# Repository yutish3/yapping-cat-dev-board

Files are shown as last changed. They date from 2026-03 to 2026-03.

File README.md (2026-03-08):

this is a custom made esp 32 devboard with extra 128mbit memory so it can do a little more processing then normal
it also has intigrted sensors for temprature and gyromovement sd card slot andd headphone jack
this will fit my custom need of small yet powerful enough custom devboard







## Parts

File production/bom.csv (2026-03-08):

Designator | Footprint | Quantity | Value | LCSC Part #
C1, C15, C16, C17, C18, C2, C21, C22, C23, C24, C25, C26, C3, C4, C5, C6 | 0603 | 16 | 100nF
C10, C11, C12, C13, C9 | 0603 | 5 | 10µF
C14 | 0603 | 1 | 22µF
C19, C20 | 0603 | 2 | 2.2µF
C7, C8 | 0603 | 2 | 22pF
D1 | LED_WS2812B_PLCC4_5.0x5.0mm_P3.2mm | 1 | WS2812B
J1 | USB_C_Receptacle_Amphenol_124019772112A | 1 | USB_C_Receptacle_USB2.0_14P
J2 | JST_PH_S2B-PH-SM4-TB_1x02-1MP_P2.00mm_Horizontal | 1 | Conn_01x02
J3 | microSD_HC_Hirose_DM3AT-SF-PEJM5 | 1 | Micro_SD_Card
J4 | Jack_3.5mm_CUI_SJ-3523-SMT_Horizontal | 1 | AudioJack3
J5 | U.FL_Hirose_U.FL-R-SMT-1_Vertical | 1 | Conn_Coaxial
J6, J7 | PinHeader_1x02_P2.54mm_Vertical | 2 | Conn_01x02
J8 | PinHeader_1x13_P2.54mm_Vertical | 1 | Conn_01x13
L1 | L_6.3x6.3_H3 | 1 | 2.2uH
R1, R2 | 0603 | 2 | 5.1k
R10, R11, R12, R13, R14, R5, R6, R7, R8, R9 | 0603 | 10 | 10k
R3 | 0603 | 1 | 1.5k
R4 | 0603 | 1 | 1.1k
SW1 | SW_SPST_FSMSM | 1 | boot
SW2 | SW_SPST_FSMSM | 1 | reset
U1 | QFN-56-1EP_7x7mm_P0.4mm_EP4x4mm | 1 | ESP32-S3
U2 | WSON-8-1EP_6x5mm_P1.27mm_EP3.4x4.3mm | 1 | W25Q128JVP
U3 | VQFN-16-1EP_3x3mm_P0.5mm_EP1.6x1.6mm | 1 | BQ24072RGT
U4 | Texas_DRC0010J_ThermalVias | 1 | TPS63001
U5 | TSSOP-20_4.4x6.5mm_P0.65mm | 1 | PCM5102A
U6 | Bosch_LGA-8_2.5x2.5mm_P0.65mm_ClockwisePinNumbering | 1 | BME280
U7 | LGA-14_3x2.5mm_P0.5mm_LayoutBorder3x4y | 1 | LSM6DS3
Y1 | Crystal_SMD_3225-4Pin_3.2x2.5mm | 1 | 40MHz

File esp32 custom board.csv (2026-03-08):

Reference | Qty | Value | DNP | Exclude from BOM | Exclude from Board | Footprint | Datasheet
C1,C2,C3,C4,C5,C6,C15,C16,C17,C18,C21,C22,C23,C24,C25,C26 | 16 | 100nF |  |  |  | Capacitor_SMD:C_0603_1608Metric | ~
C7,C8 | 2 | 22pF |  |  |  | Capacitor_SMD:C_0603_1608Metric | ~
C9,C10,C11,C12,C13 | 5 | 10µF |  |  |  | Capacitor_SMD:C_0603_1608Metric | ~
C14 | 1 | 22µF |  |  |  | Capacitor_SMD:C_0603_1608Metric | ~
C19,C20 | 2 | 2.2µF |  |  |  | Capacitor_SMD:C_0603_1608Metric | ~
D1 | 1 | WS2812B |  |  |  | LED_SMD:LED_WS2812B_PLCC4_5.0x5.0mm_P3.2mm | https://cdn-shop.adafruit.com/datasheets/WS2812B.pdf
J1 | 1 | USB_C_Receptacle_USB2.0_14P |  |  |  | Connector_USB:USB_C_Receptacle_Amphenol_124019772112A | https://www.usb.org/sites/default/files/documents/usb_type-c.zip
J2 | 1 | Conn_01x02 |  |  |  | Connector_JST:JST_PH_S2B-PH-SM4-TB_1x02-1MP_P2.00mm_Horizontal | ~
J3 | 1 | Micro_SD_Card |  |  |  | Connector_Card:microSD_HC_Hirose_DM3AT-SF-PEJM5 | https://www.we-online.com/components/products/datasheet/693072010801.pdf
J4 | 1 | AudioJack3 |  |  |  | Connector_Audio:Jack_3.5mm_CUI_SJ-3523-SMT_Horizontal | ~
J5 | 1 | Conn_Coaxial |  |  |  | Connector_Coaxial:U.FL_Hirose_U.FL-R-SMT-1_Vertical | ~
J6,J7 | 2 | Conn_01x02 |  |  |  | Connector_PinHeader_2.54mm:PinHeader_1x02_P2.54mm_Vertical | ~
J8 | 1 | Conn_01x13 |  |  |  | Connector_PinHeader_2.54mm:PinHeader_1x13_P2.54mm_Vertical | ~
L1 | 1 | 2.2uH |  |  |  | Inductor_SMD:L_6.3x6.3_H3 | ~
R1,R2 | 2 | 5.1k |  |  |  | Resistor_SMD:R_0603_1608Metric | ~
R3 | 1 | 1.5k |  |  |  | Resistor_SMD:R_0603_1608Metric | ~
R4 | 1 | 1.1k |  |  |  | Resistor_SMD:R_0603_1608Metric | ~
R5,R11,R12 | 3 | 10K |  |  |  | Resistor_SMD:R_0603_1608Metric | ~
R6,R7,R8,R9,R10,R13,R14 | 7 | 10k |  |  |  | Resistor_SMD:R_0603_1608Metric | ~
SW1 | 1 | boot |  |  |  | Button_Switch_SMD:SW_SPST_FSMSM | ~
SW2 | 1 | reset |  |  |  | Button_Switch_SMD:SW_SPST_FSMSM | ~
U1 | 1 | ESP32-S3 |  |  |  | Package_DFN_QFN:QFN-56-1EP_7x7mm_P0.4mm_EP4x4mm | https://www.espressif.com/sites/default/files/documentation/esp32-s3_datasheet_en.pdf
U2 | 1 | W25Q128JVP |  |  |  | Package_SON:WSON-8-1EP_6x5mm_P1.27mm_EP3.4x4.3mm | https://www.winbond.com/resource-files/w25q128jv_dtr%20revc%2003272018%20plus.pdf
U3 | 1 | BQ24072RGT |  |  |  | Package_DFN_QFN:VQFN-16-1EP_3x3mm_P0.5mm_EP1.6x1.6mm | http://www.ti.com/lit/ds/symlink/bq24072.pdf
U4 | 1 | TPS63001 |  |  |  | Package_SON:Texas_DRC0010J_ThermalVias | http://www.ti.com/lit/ds/symlink/tps63000.pdf
U5 | 1 | PCM5102A |  |  |  | Package_SO:TSSOP-20_4.4x6.5mm_P0.65mm | https://www.ti.com/lit/ds/symlink/pcm5102a.pdf
U6 | 1 | BME280 |  |  |  | Package_LGA:Bosch_LGA-8_2.5x2.5mm_P0.65mm_ClockwisePinNumbering | https://www.bosch-sensortec.com/media/boschsensortec/downloads/datasheets/bst-bme280-ds002.pdf
U7 | 1 | LSM6DS3 |  |  |  | Package_LGA:LGA-14_3x2.5mm_P0.5mm_LayoutBorder3x4y | https://www.st.com/resource/en/datasheet/lsm6ds3tr-c.pdf
Y1 | 1 | 40MHz |  |  |  | Crystal:Crystal_SMD_3225-4Pin_3.2x2.5mm | ~

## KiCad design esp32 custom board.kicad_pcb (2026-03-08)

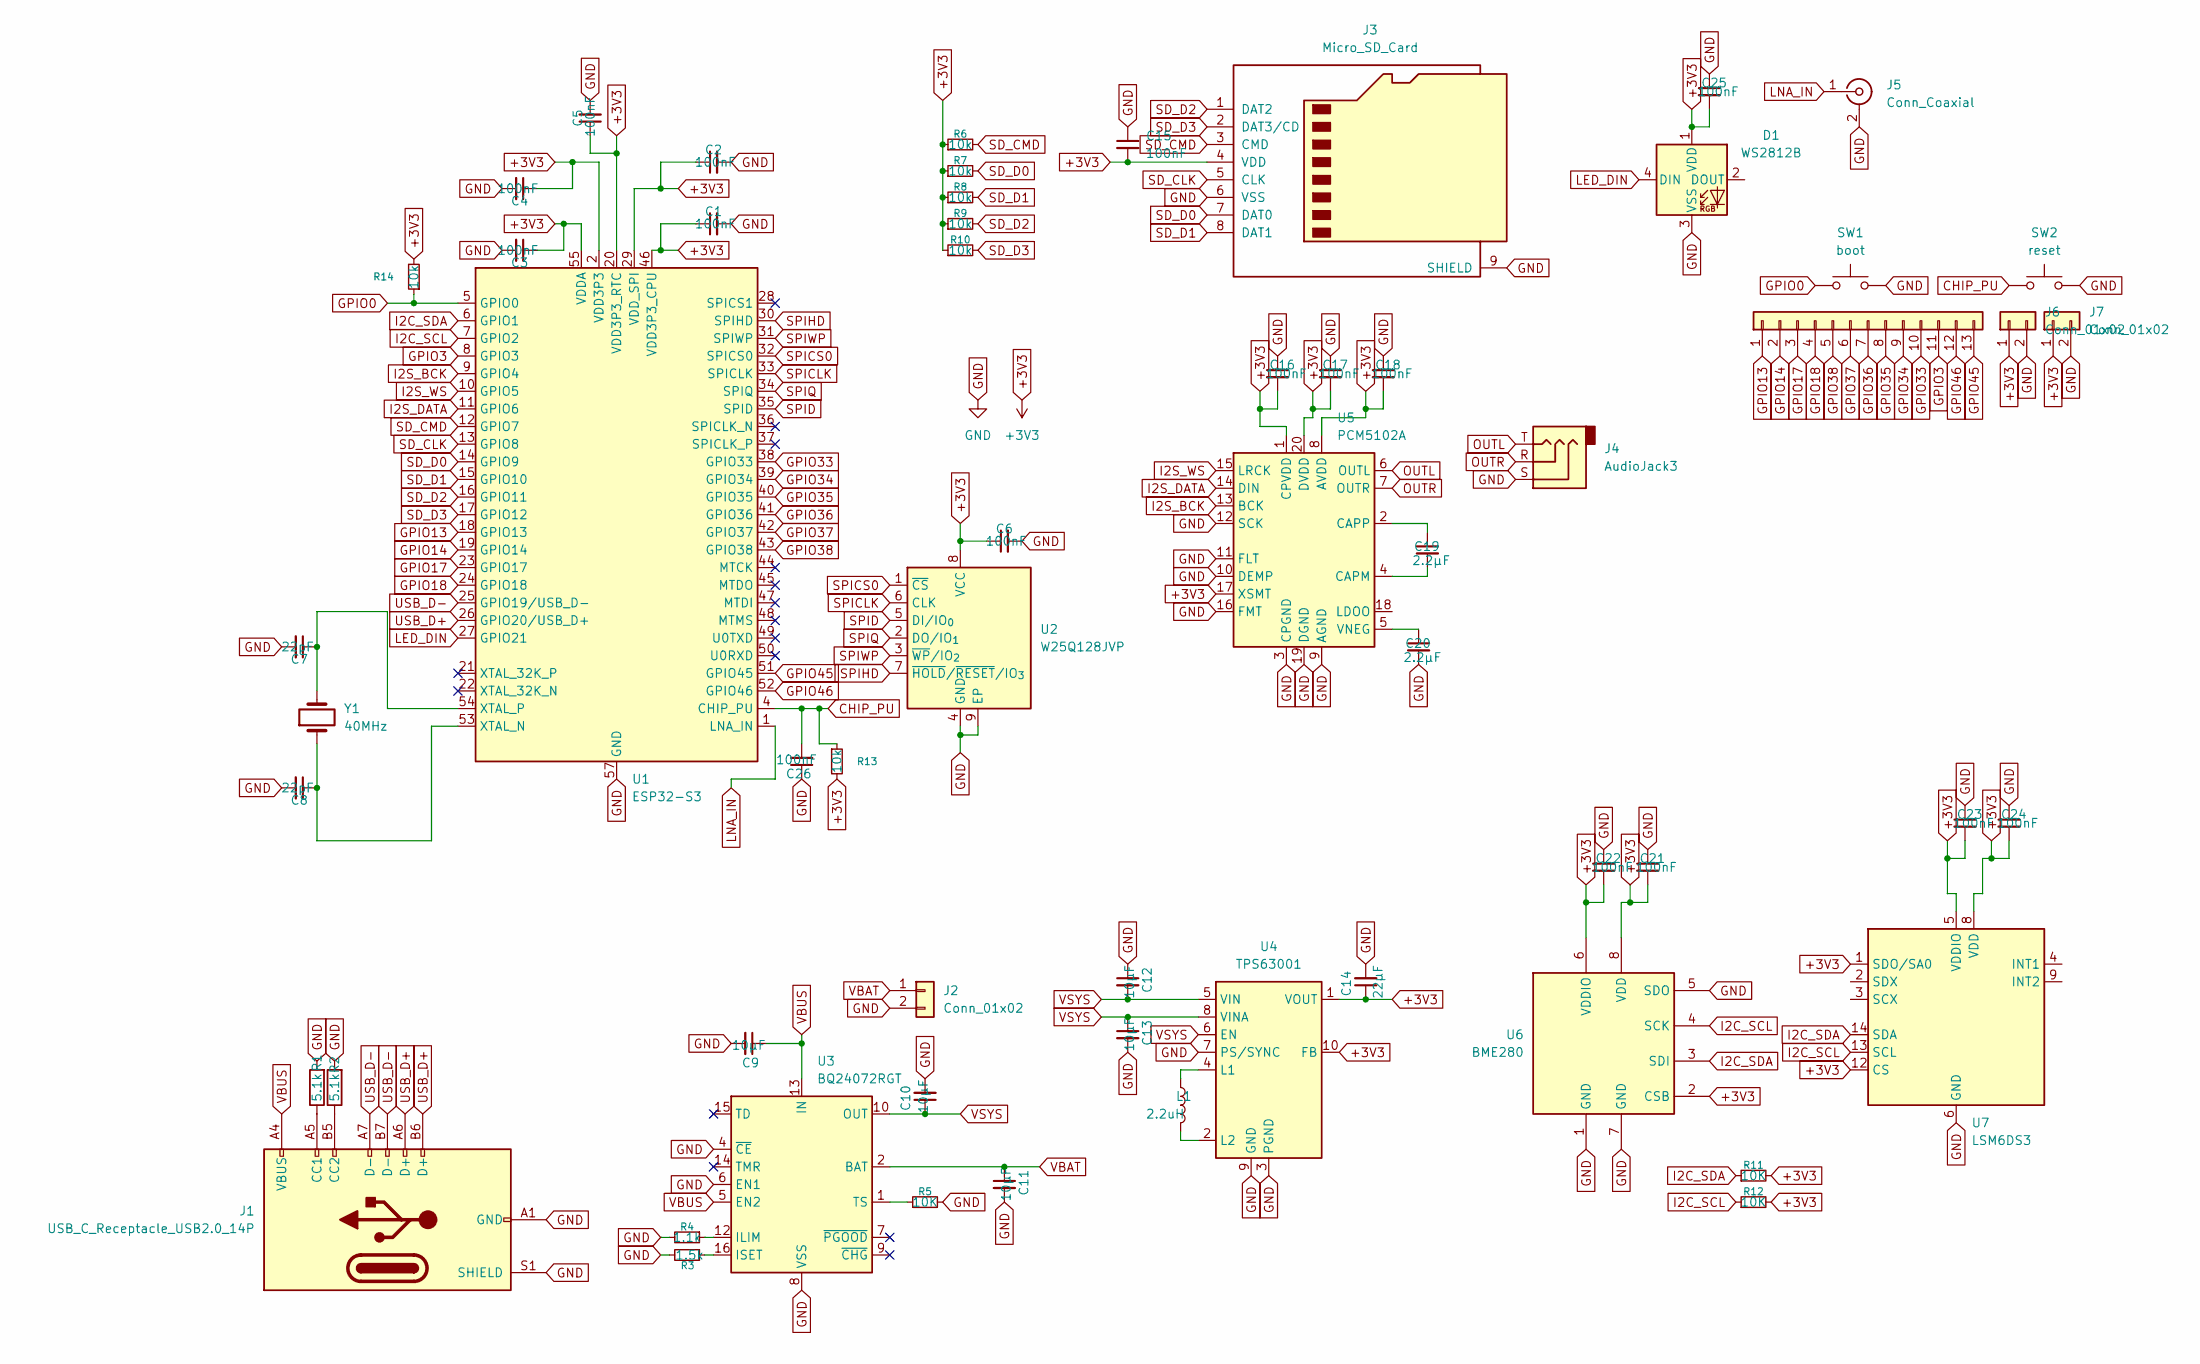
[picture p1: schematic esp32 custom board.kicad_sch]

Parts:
C1, C2, C3, C4, C5, C6, C15, C16, C17, C18, C21, C22, C23, C24, C25, C26: 100nF; C_0603_1608Metric
C7, C8: 22pF; C_0603_1608Metric
C9, C10, C11, C12, C13: 10µF; C_0603_1608Metric
C14: 22µF; C_0603_1608Metric
C19, C20: 2.2µF; C_0603_1608Metric
D1: WS2812B; LED_WS2812B_PLCC4_5.0x5.0mm_P3.2mm
J1: USB_C_Receptacle_USB2.0_14P; USB_C_Receptacle_Amphenol_124019772112A
J2: Conn_01x02; JST_PH_S2B-PH-SM4-TB_1x02-1MP_P2.00mm_Horizontal
J3: Micro_SD_Card; microSD_HC_Hirose_DM3AT-SF-PEJM5
J4: AudioJack3; Jack_3.5mm_CUI_SJ-3523-SMT_Horizontal
J5: Conn_Coaxial; U.FL_Hirose_U.FL-R-SMT-1_Vertical
J6, J7: Conn_01x02; PinHeader_1x02_P2.54mm_Vertical
J8: Conn_01x13; PinHeader_1x13_P2.54mm_Vertical
L1: 2.2uH; L_6.3x6.3_H3
R1, R2: 5.1k; R_0603_1608Metric
R3: 1.5k; R_0603_1608Metric
R4: 1.1k; R_0603_1608Metric
R5, R11, R12: 10K; R_0603_1608Metric
R6, R7, R8, R9, R10, R13, R14: 10k; R_0603_1608Metric
SW1: boot; SW_SPST_FSMSM
SW2: reset; SW_SPST_FSMSM
U1: ESP32-S3; QFN-56-1EP_7x7mm_P0.4mm_EP4x4mm
U2: W25Q128JVP; WSON-8-1EP_6x5mm_P1.27mm_EP3.4x4.3mm
U3: BQ24072RGT; VQFN-16-1EP_3x3mm_P0.5mm_EP1.6x1.6mm
U4: TPS63001; Texas_DRC0010J_ThermalVias
U5: PCM5102A; TSSOP-20_4.4x6.5mm_P0.65mm
U6: BME280; Bosch_LGA-8_2.5x2.5mm_P0.65mm_ClockwisePinNumbering
U7: LSM6DS3; LGA-14_3x2.5mm_P0.5mm_LayoutBorder3x4y
Y1: 40MHz; Crystal_SMD_3225-4Pin_3.2x2.5mm

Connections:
+3V3: C1.1, C2.1, C3.1, C4.1, C5.1, C6.1, C14.1, C15.2, C16.2, C17.2, C18.2, C21.2, C22.2, C23.2, C24.2, C25.2, D1.1 (VDD), J3.4 (VDD), J6.1, J7.1, R6.1, R7.1, R8.1, R9.1, R10.1, R11.2, R12.2, R13.2, R14.2, U1.2 (VDD3P3), U1.3 (VDD3P3), U1.20 (VDD3P3_RTC), U1.29 (VDD_SPI), U1.46 (VDD3P3_CPU), U1.55 (VDDA), U1.56 (VDDA), U2.8 (VCC), U4.1 (VOUT), U4.10 (FB), U5.1 (CPVDD), U5.8 (AVDD), U5.17 (XSMT), U5.20 (DVDD), U6.2 (CSB), U6.6 (VDDIO), U6.8 (VDD), U7.1 (SDO/SA0), U7.5 (VDDIO), U7.8 (VDD), U7.12 (CS)
CHIP_PU: C26.2, R13.1, SW2.1, U1.4 (CHIP_PU)
GND: C1.2, C2.2, C3.2, C4.2, C5.2, C6.2, C7.2, C8.2, C9.2, C10.2, C11.2, C12.1, C13.2, C14.2, C15.1, C16.1, C17.1, C18.1, C20.2, C21.1, C22.1, C23.1, C24.1, C25.1, C26.1, D1.3 (VSS), J1.A1 (GND), J1.A12 (GND), J1.B1 (GND), J1.B12 (GND), J1.S1 (SHIELD), J2.2, J3.6 (VSS), J3.9 (SHIELD), J4.S, J5.2 (Ext), J6.2, J7.2, R1.2, R2.2, R3.2, R4.2, R5.2, SW1.2, SW2.2, U1.57 (GND), U2.4 (GND), U2.9 (EP), U3.4 (~CE), U3.6 (EN1), U3.8 (VSS), U3.17 (VSS), U4.3 (PGND), U4.7 (PS/SYNC), U4.9 (GND), U4.11 (PGND), U5.3 (CPGND), U5.9 (AGND), U5.10 (DEMP), U5.11 (FLT), U5.12 (SCK), U5.16 (FMT), U5.19 (DGND), U6.1 (GND), U6.5 (SDO), U6.7 (GND), U7.6 (GND), U7.7 (GND)
GPIO0: R14.1, SW1.1, U1.5 (GPIO0)
GPIO3: J8.11, U1.8 (GPIO3)
GPIO13: J8.1, U1.18 (GPIO13)
GPIO14: J8.2, U1.19 (GPIO14)
GPIO17: J8.3, U1.23 (GPIO17)
GPIO18: J8.4, U1.24 (GPIO18)
GPIO33: J8.10, U1.38 (GPIO33)
GPIO34: J8.9, U1.39 (GPIO34)
GPIO35: J8.8, U1.40 (GPIO35)
GPIO36: J8.7, U1.41 (GPIO36)
GPIO37: J8.6, U1.42 (GPIO37)
GPIO38: J8.5, U1.43 (GPIO38)
GPIO45: J8.13, U1.51 (GPIO45)
GPIO46: J8.12, U1.52 (GPIO46)
I2C_SCL: R12.1, U1.7 (GPIO2), U6.4 (SCK), U7.13 (SCL)
I2C_SDA: R11.1, U1.6 (GPIO1), U6.3 (SDI), U7.14 (SDA)
I2S_BCK: U1.9 (GPIO4), U5.13 (BCK)
I2S_DATA: U1.11 (GPIO6), U5.14 (DIN)
I2S_WS: U1.10 (GPIO5), U5.15 (LRCK)
LED_DIN: D1.4 (DIN), U1.27 (GPIO21)
LNA_IN: J5.1 (In), U1.1 (LNA_IN)
unnamed: J1.A5 (CC1), R1.1
unnamed: J1.B5 (CC2), R2.1
unnamed: C8.1, U1.53 (XTAL_N), Y1.1
unnamed: C7.1, U1.54 (XTAL_P), Y1.2
unnamed: R4.1, U3.12 (ILIM)
unnamed: R3.1, U3.16 (ISET)
unnamed: R5.1, U3.1 (TS)
unnamed: L1.1, U4.4 (L1)
unnamed: L1.2, U4.2 (L2)
unnamed: C19.2, U5.4 (CAPM)
unnamed: C19.1, U5.2 (CAPP)
unnamed: C20.1, U5.5 (VNEG)
OUTL: J4.T, U5.6 (OUTL)
OUTR: J4.R, U5.7 (OUTR)
SD_CLK: J3.5 (CLK), U1.13 (GPIO8)
SD_CMD: J3.3 (CMD), R6.2, U1.12 (GPIO7)
SD_D0: J3.7 (DAT0), R7.2, U1.14 (GPIO9)
SD_D1: J3.8 (DAT1), R8.2, U1.15 (GPIO10)
SD_D2: J3.1 (DAT2), R9.2, U1.16 (GPIO11)
SD_D3: J3.2 (DAT3/CD), R10.2, U1.17 (GPIO12)
SPICLK: U1.33 (SPICLK), U2.6 (CLK)
SPICS0: U1.32 (SPICS0), U2.1 (~CS)
SPID: U1.35 (SPID), U2.5 (DI/IO_{0})
SPIHD: U1.30 (SPIHD), U2.7 (~HOLD/~RESET/IO_{3})
SPIQ: U1.34 (SPIQ), U2.2 (DO/IO_{1})
SPIWP: U1.31 (SPIWP), U2.3 (~WP/IO_{2})
USB_D+: J1.A6 (D+), J1.B6 (D+), U1.26 (GPIO20/USB_D+)
USB_D-: J1.A7 (D-), J1.B7 (D-), U1.25 (GPIO19/USB_D-)
VBAT: C11.1, J2.1, U3.2 (BAT), U3.3 (BAT)
VBUS: C9.1, J1.A4 (VBUS), J1.A9 (VBUS), J1.B4 (VBUS), J1.B9 (VBUS), U3.5 (EN2), U3.13 (IN)
VSYS: C10.1, C12.2, C13.1, U3.10 (OUT), U3.11 (OUT), U4.5 (VIN), U4.6 (EN), U4.8 (VINA)

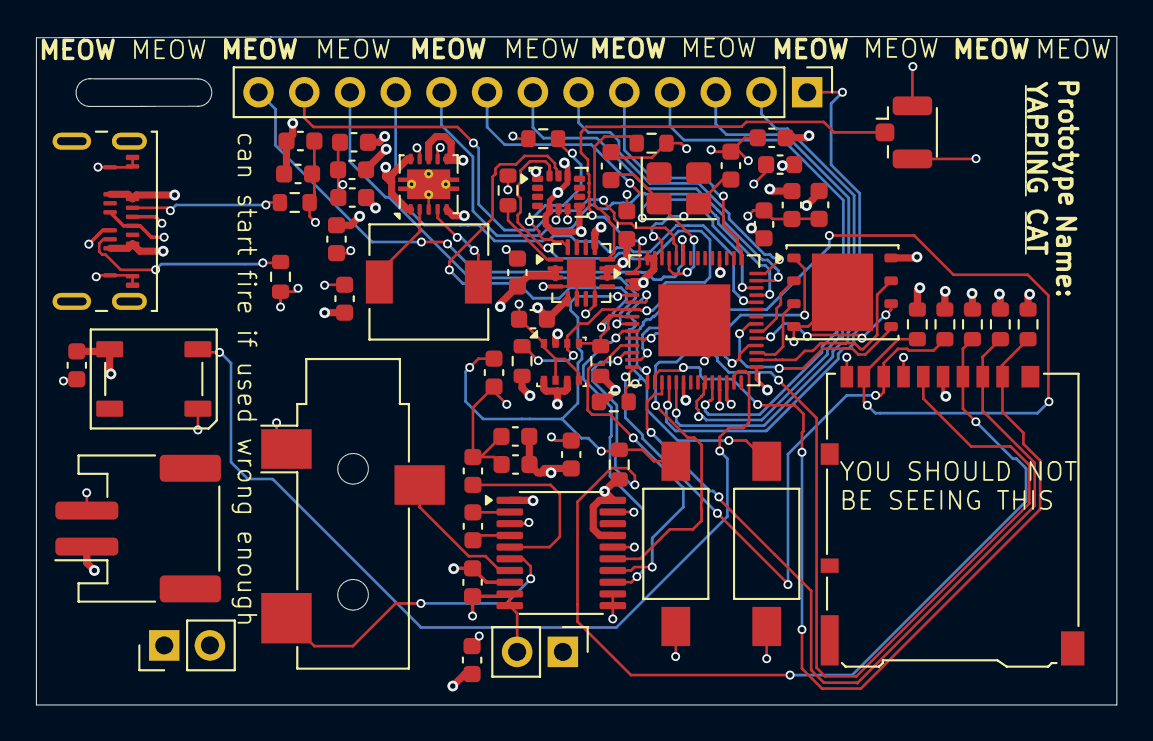
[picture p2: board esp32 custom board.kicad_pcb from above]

Board: 4 copper layers, 60.0 x 37.1 mm, 60 parts (0 on the bottom side), 55 nets.

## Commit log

2026-03-08 Insert images into README.md
    Add images to the README file
2026-03-08 Enhance README with ESP32 devboard details
    Added description of custom ESP32 devboard features and images.
